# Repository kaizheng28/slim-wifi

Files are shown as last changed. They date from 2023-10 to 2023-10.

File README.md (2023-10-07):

# slim-wifi
Schematic and layout file for the SlimWiFi prototype. Open with Altium Designer. 

The LCR values need fine-tuning but you may start with the values in the schematic. The frequency should be close to 2.4GHz using the posted values. Play around with C2, C4, and C5 to fine-tune.  
L4, C6, and C7 are reserved for impedance matching, but in our previous experiment, bypassing them yields the strongest output signal for some reason.

**Related publication:**
Zhao, Renjie, Kejia Wang, Kai Zheng, Xinyu Zhang, and Vincent Leung. "{SlimWiFi}:{Ultra-Low-Power}{IoT} Radio Architecture Enabled by Asymmetric Communication." In 20th USENIX Symposium on Networked Systems Design and Implementation (NSDI 23), pp. 1201-1219. 2023.

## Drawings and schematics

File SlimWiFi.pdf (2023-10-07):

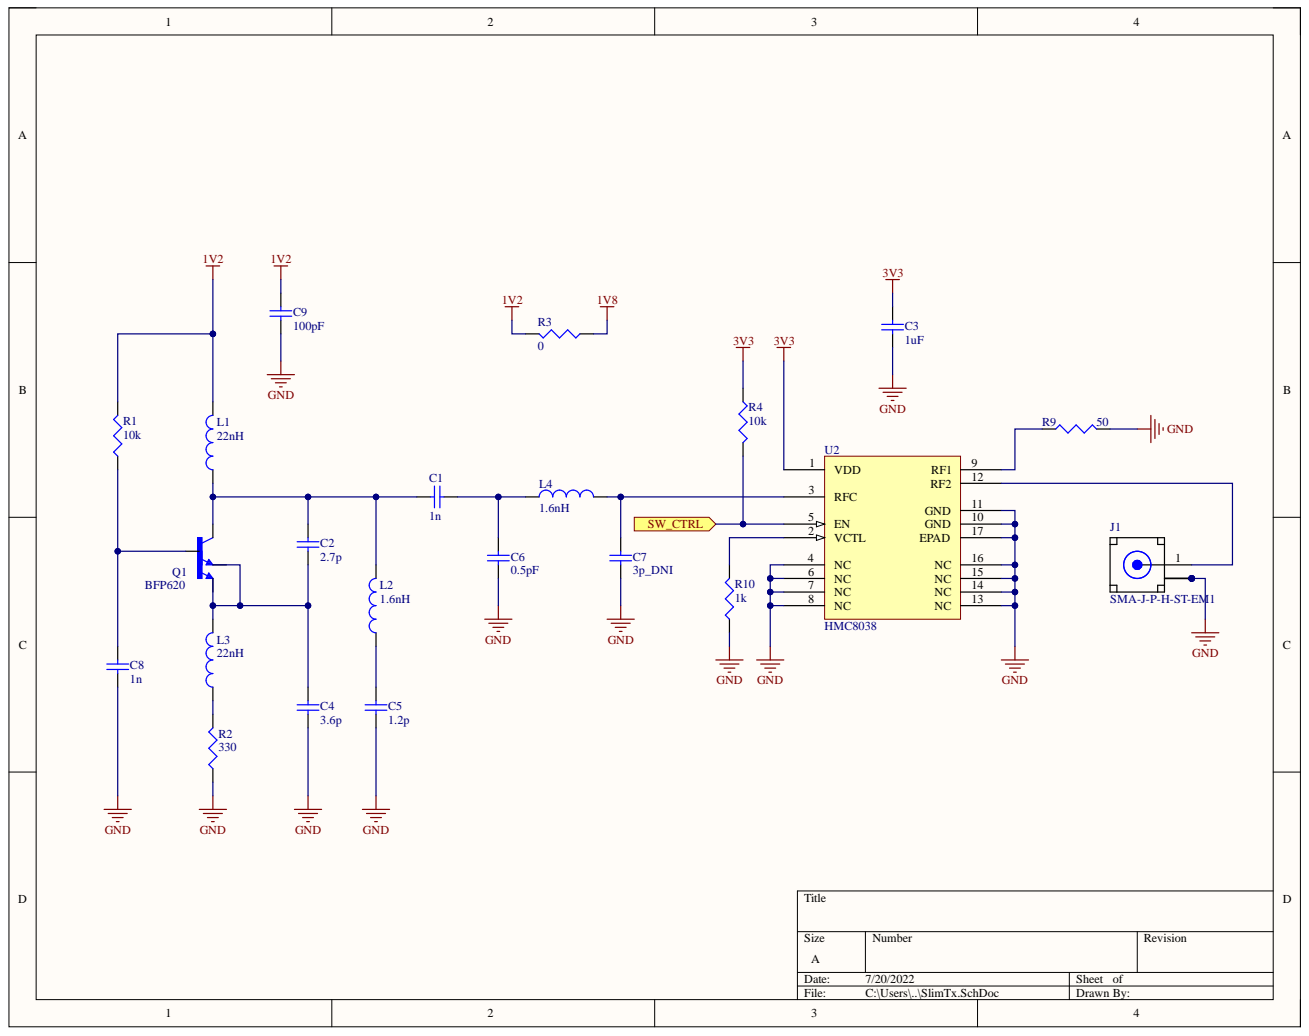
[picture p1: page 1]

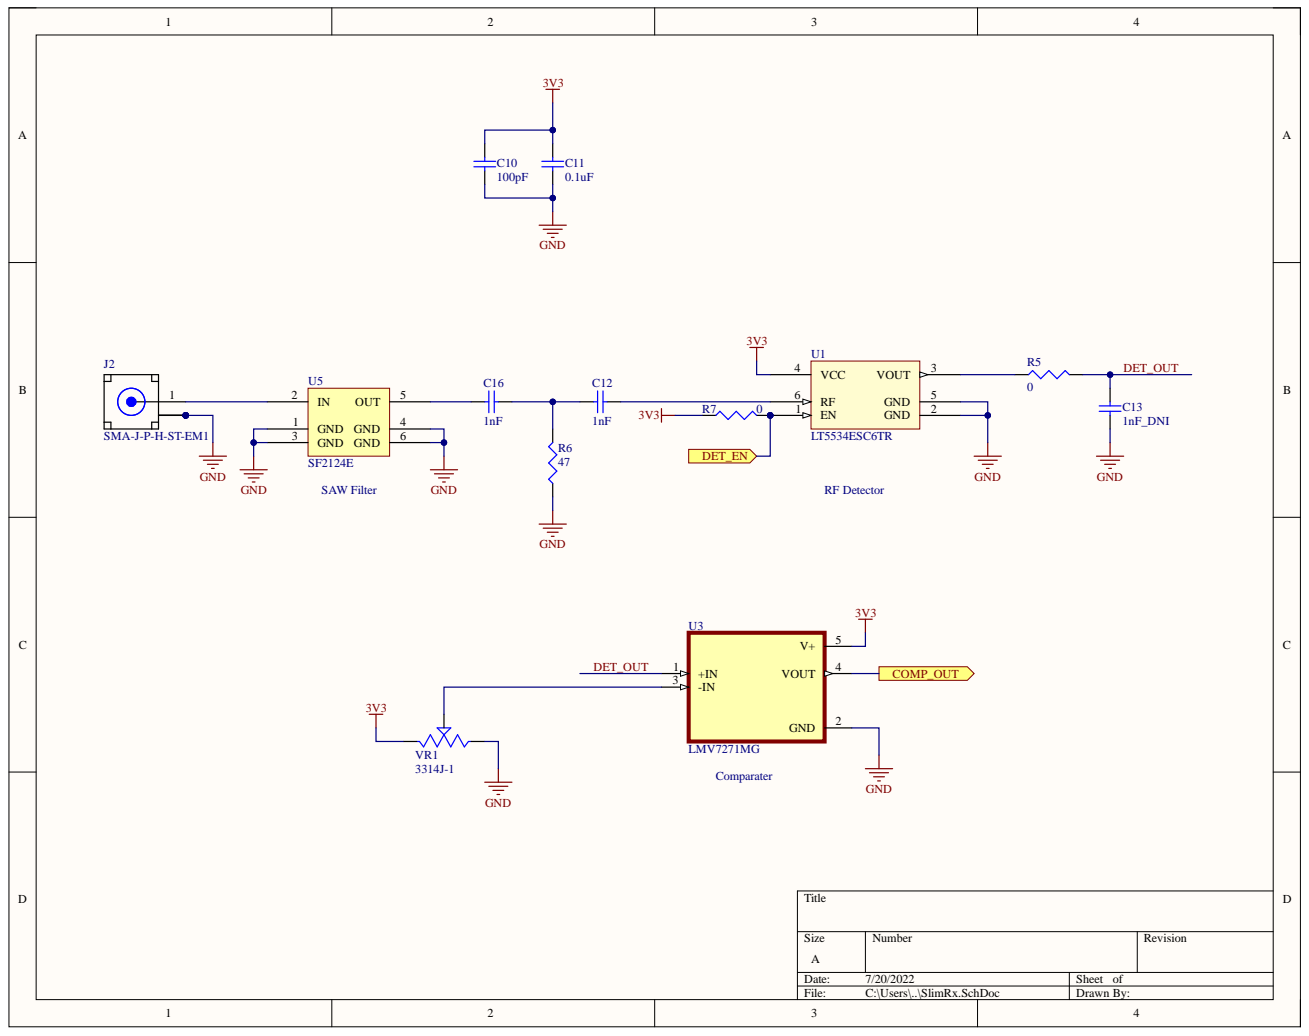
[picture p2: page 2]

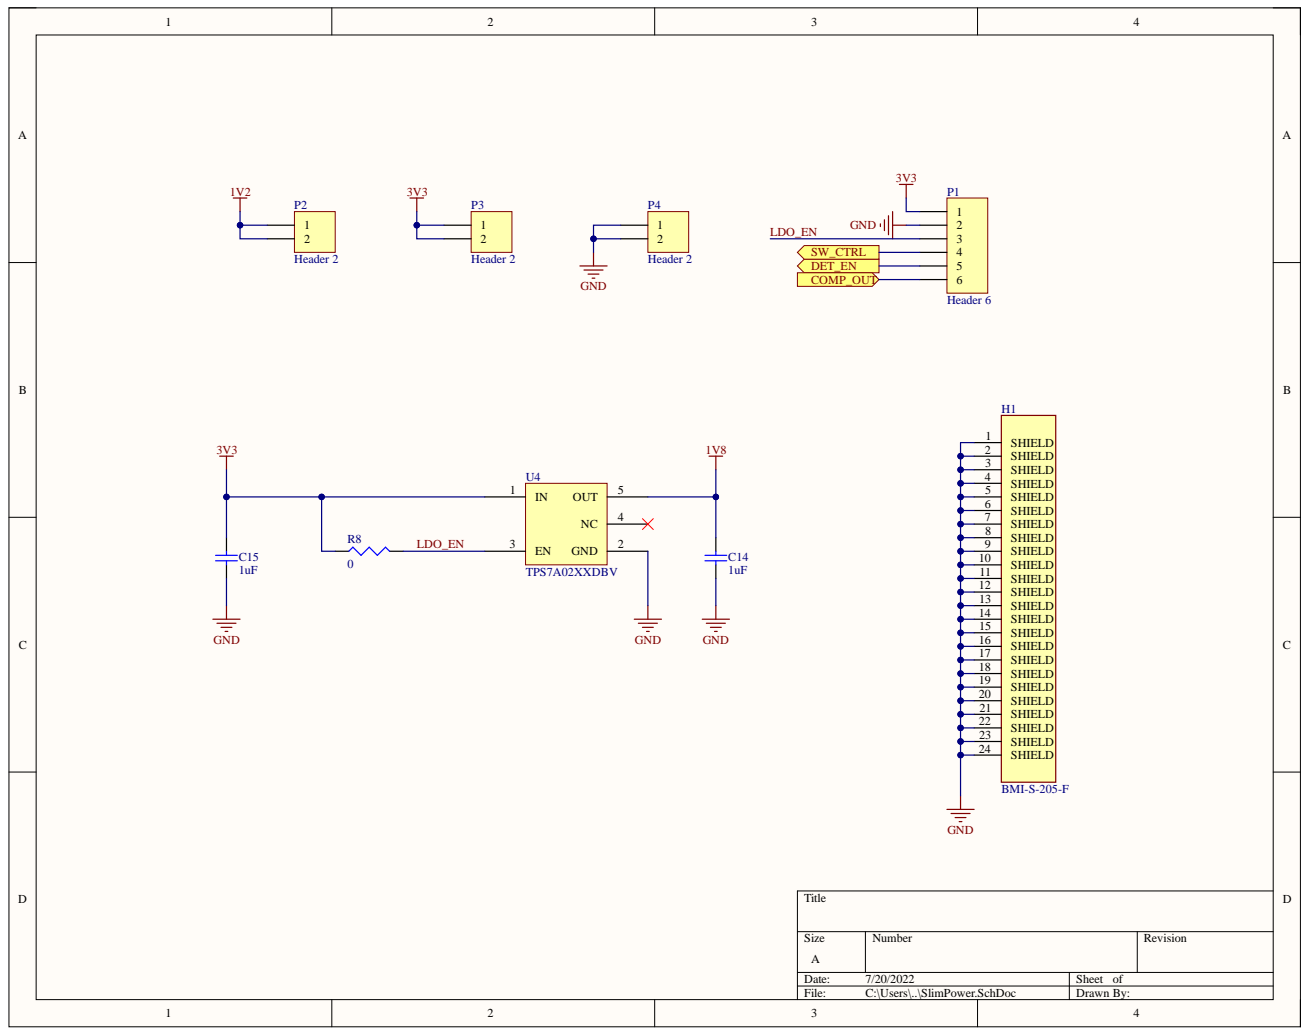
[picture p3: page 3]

Comment | Description | Designator | Footprint | LibRef | Quantity
1n | Ceramic Capacitor 0603 | C1, C8 | SMD-0603 | CAP0603 | 2
2.7p | Ceramic Capacitor 0603 | C2 | SMD-0603 | CAP0603 | 1
1uF | Ceramic Capacitor 0603 | C3, C14, C15 | SMD-0603 | CAP0603 | 3
3.6p | Ceramic Capacitor 0603 | C4 | SMD-0603 | CAP0603 | 1
1.2p | Ceramic Capacitor 0603 | C5 | SMD-0603 | CAP0603 | 1
0.5pF | Ceramic Capacitor 0603 | C6 | SMD-0603 | CAP0603 | 1
3p_DNI | Ceramic Capacitor 0603 | C7 | SMD-0603 | CAP0603 | 1
100pF | Ceramic Capacitor 0603 | C9, C10 | SMD-0603 | CAP0603 | 2
0.1uF | Ceramic Capacitor 0805 Imperial (2012 Metric) | C11 | SMD-0805 | CAP0805 | 1
1nF | Ceramic Capacitor 0603 | C12, C16 | SMD-0603 | CAP0603 | 2
1nF_DNI | Ceramic Capacitor 0603 | C13 | SMD-0603 | CAP0603 | 1
BMI-S-205-F | RF Shield Frame 1.000 _25.40mm_ X 1.500 _38.10mm_ Solder | H1 | LAIRD_BMI-S-205-F | BMI-S-205-F | 1
SMA-J-P-H-ST-EM1 | Connector SMA F 50Ohm Solder ST Edge Mount Gold Over Nickel Tray | J1, J2 | SMA-J-P-H-ST-EM1 | SMA-J-P-H-ST-EM1 | 2
22nH | Inductor 0603 | L1, L3 | SMD-0603 | L0603 | 2
1.6nH | Inductor 0603 | L2, L4 | SMD-0603 | L0603 | 2
Header 6 | Header, 6-Pin | P1 | HDR1X6 | Header 6 | 1
Header 2 | Header, 2-Pin | P2, P3, P4 | HDR1X2 | Header 2 | 3
BFP620 | Trans RF BJT NPN 2.3V 0.08A 185mW Automotive 4-Pin(3+Tab) SOT-343 T/R | Q1 | SOT343 | BFP620 | 1
10k | Resistor-0603 | R1, R4 | SMD-0603 | RES0603 | 2
330 | Resistor-0603 | R2 | SMD-0603 | RES0603 | 1
0 | Resistor-0603 | R3, R5, R7, R8 | SMD-0603 | RES0603 | 4
47 | Resistor-0603 | R6 | SMD-0603 | RES0603 | 1
50 | Resistor-0603 | R9 | SMD-0603 | RES0603 | 1
1k | Resistor-0603 | R10 | SMD-0603 | RES0603 | 1
LT5534ESC6TR | | U1 | SOT-6_SC | LT5534ESC6TR | 1
HMC8038 | High Isolation, Silicon SPDT, Nonreflective Switch, 0.1 GHz to 6.0 GHz | U2 | PQFN127P600-8N LFCSP-17 | HMC8038 | 1
LMV7271MG | | U3 | SOT65P210X110-5N | LMV7271MG | 1
TPS7A02XXDBV | TPS7A02Nanopower IQ, 25-nA, 200-mA, Low-Dropout Voltage Regulator With Fast Transient Response | U4 | SOT95P280X145-5N | TPS7A02XXDBV | 1
SF2124E | Signal Conditioning FILTER, SAW, 2441.8 MHZ, 6SMD | U5 | FIL_SF2124E | SF2124E | 1
3314J-1 | 10 kOhms 0.25W, 1/4W J Lead Surface Mount Trimmer Potentiometer Cermet 1 Turn Top Adjustment | VR1 | TRIM_3314J-1 | 3314J-1 | 1
